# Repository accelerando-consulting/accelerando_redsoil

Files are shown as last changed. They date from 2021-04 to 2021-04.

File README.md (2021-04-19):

# Accelerando Redsoil

This is a simple breakout board for the eByte E73 module with nrf52840
microcontroller.  This board requires minimal parts, in fact it can
work with only the module and no other parts.

There is a space for a LED on the front (pin 1.04) and it is possible
to add buttons on the back by soldering to an IO pin and the ground plane.

The board can be used with Arduino (Sandeep Mistry's nrf port with the
generic nrf52 target), or Zephyr OS using the included board
definition.

There is also a board definition for the Adafruit nrf52 bootloader,
and for CircuitPython, which make the board a fully compliant
CircuitPython target.

The circuit board files (for KiCad 5) are included.

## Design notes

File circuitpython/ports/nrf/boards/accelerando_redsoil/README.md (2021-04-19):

# Accelerando Redsoil Breakout

The [Accelerando Redsoil](https://accelerando.com.au/) is a minimal
breakout board for eByte's ebyte_e73_2g4m08s1, which contains
an nrf52840, either with a chip antenna or IPX.   It breaks out all of
the outer castellated holes on the eByte module, and uses the under-board lands for
on-board parts (eg the LED on P0.04).

## CircuitPython Pin Defs

CircuitPython pin definitions hove to the NRF pin numbers, because
doing otherwise (like Sparkfun chose to do) breaks my brain.

<table>
</table>

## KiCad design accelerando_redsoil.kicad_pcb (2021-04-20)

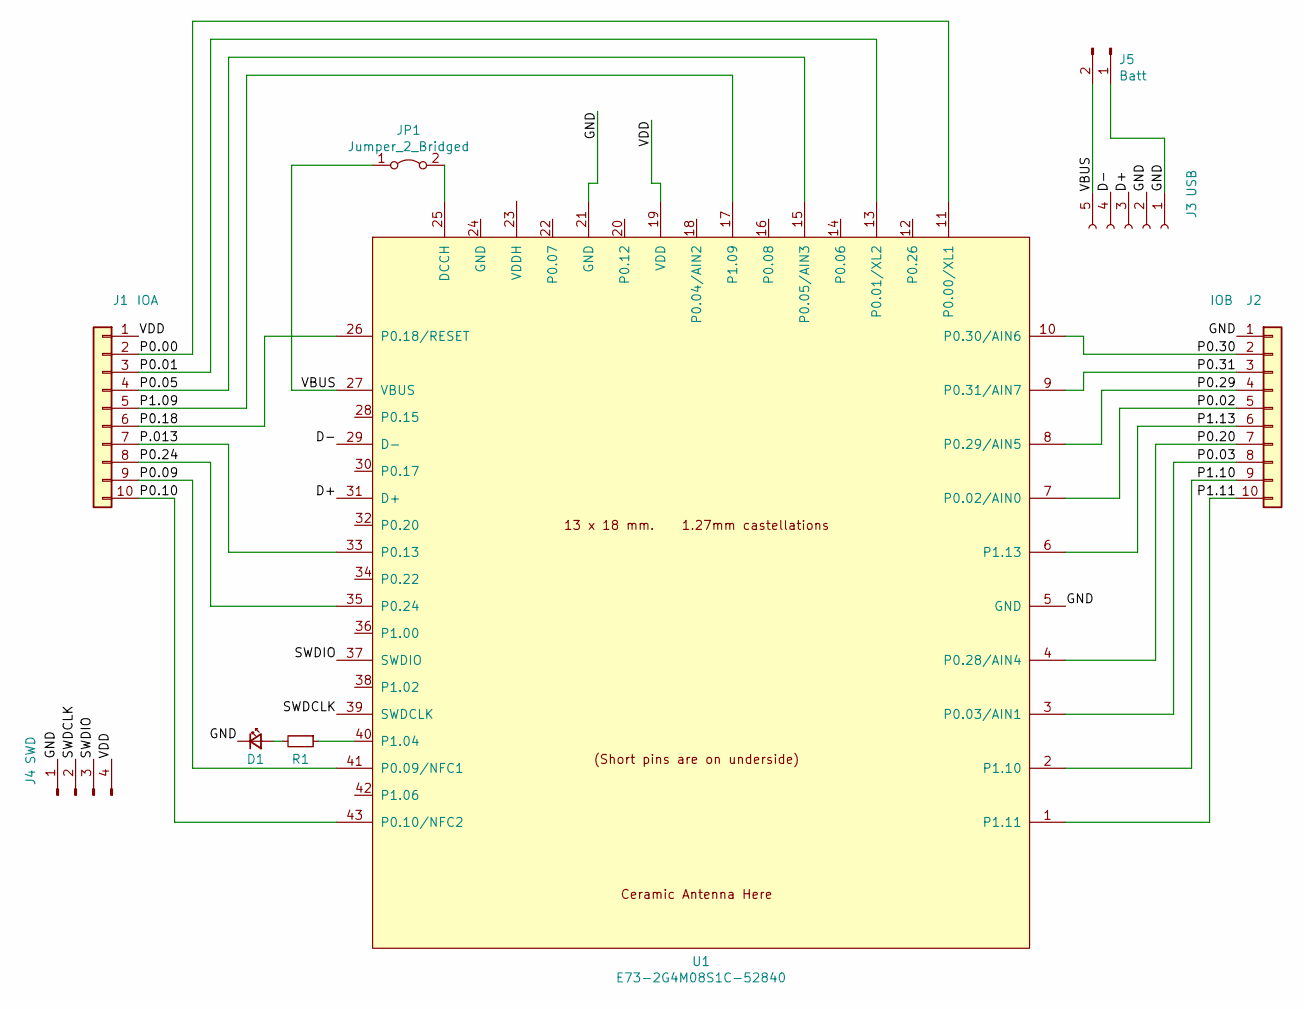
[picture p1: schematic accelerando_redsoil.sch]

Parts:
D1: LED_Small; LED_0603_1608Metric
J1: IOA; PinHeader_1x10_P2.54mm_Vertical
J2: IOB; PinHeader_1x10_P2.54mm_Vertical
J3: USB; PinHeader_1x05_P2.54mm_Vertical
J4: SWD; JST_PH_S4B-PH-K_1x04_P2.00mm_Horizontal
J5: Batt; PinHeader_1x02_P1.27mm_Vertical
JP1: Jumper_2_Bridged; SolderJumper-2_P1.3mm_Open_RoundedPad1.0x1.5mm
R1: R_Small; R_0603_1608Metric
U1: E73-2G4M08S1C-52840

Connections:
/D+: J3.3, U1.31 (D+)
/D-: J3.4, U1.29 (D-)
/GND: D1.1 (K), J2.1, J3.1, J3.2, J4.1, J5.1, U1.5 (GND), U1.21 (GND)
/P0.00: J1.2, U1.11 (P0.00/XL1)
/P0.01: J1.3, U1.13 (P0.01/XL2)
/P0.02: J2.5, U1.7 (P0.02/AIN0)
/P0.03: J2.8, U1.3 (P0.03/AIN1)
/P0.05: J1.4, U1.15 (P0.05/AIN3)
/P0.09: J1.9, U1.41 (P0.09/NFC1)
/P0.10: J1.10, U1.43 (P0.10/NFC2)
/P0.18: J1.6, U1.26 (P0.18/RESET)
/P0.20: J2.7, U1.4 (P0.28/AIN4)
/P0.24: J1.8, U1.35 (P0.24)
/P0.29: J2.4, U1.8 (P0.29/AIN5)
/P0.30: J2.2, U1.10 (P0.30/AIN6)
/P0.31: J2.3, U1.9 (P0.31/AIN7)
/P1.09: J1.5, U1.17 (P1.09)
/P1.10: J2.9, U1.2 (P1.10)
/P1.11: J2.10, U1.1 (P1.11)
/P1.13: J2.6, U1.6 (P1.13)
/P.013: J1.7, U1.33 (P0.13)
/SWDCLK: J4.2, U1.39 (SWDCLK)
/SWDIO: J4.3, U1.37 (SWDIO)
/VBUS: J3.5, J5.2, JP1.1 (A), U1.27 (VBUS)
/VDD: J1.1, J4.4, U1.19 (VDD)
unnamed: D1.2 (A), R1.2
unnamed: JP1.2 (B), U1.25 (DCCH)
unnamed: R1.1, U1.40 (P1.04)

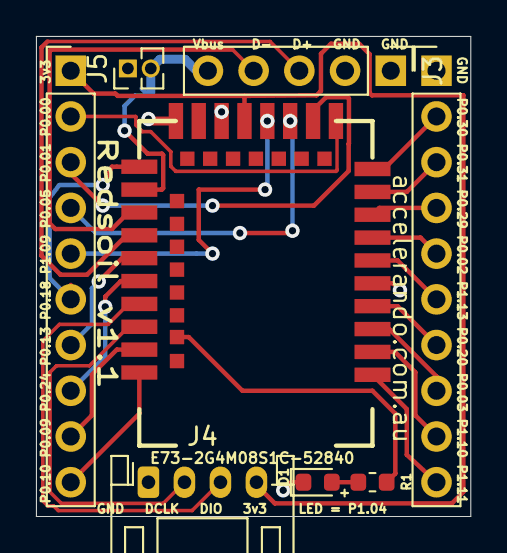
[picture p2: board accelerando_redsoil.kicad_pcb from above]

Board: 2 copper layers, 24.1 x 26.7 mm, 9 parts (1 on the bottom side), 28 nets.

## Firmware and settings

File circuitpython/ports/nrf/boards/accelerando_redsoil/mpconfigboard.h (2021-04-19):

/*
 * This file is part of the MicroPython project, http://micropython.org/
 *
 * The MIT License (MIT)
 *
 * Copyright (c) 2016 Glenn Ruben Bakke
 *
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
 * THE SOFTWARE IS PROVIDED "AS IS", WITHOUT WARRANTY OF ANY KIND, EXPRESS OR
 * IMPLIED, INCLUDING BUT NOT LIMITED TO THE WARRANTIES OF MERCHANTABILITY,
 * FITNESS FOR A PARTICULAR PURPOSE AND NONINFRINGEMENT. IN NO EVENT SHALL THE
 * AUTHORS OR COPYRIGHT HOLDERS BE LIABLE FOR ANY CLAIM, DAMAGES OR OTHER
 * LIABILITY, WHETHER IN AN ACTION OF CONTRACT, TORT OR OTHERWISE, ARISING FROM,
 * OUT OF OR IN CONNECTION WITH THE SOFTWARE OR THE USE OR OTHER DEALINGS IN
 * THE SOFTWARE.
 */

#include "nrfx/hal/nrf_gpio.h"

#define MICROPY_HW_BOARD_NAME       "Accelerando Redsoil"
#define MICROPY_HW_MCU_NAME         "nRF52840"

#define DEFAULT_I2C_BUS_SCL         (&pin_P0_29)
#define DEFAULT_I2C_BUS_SDA         (&pin_P0_02)

#define DEFAULT_SPI_BUS_SCK         (&pin_P0_05)
#define DEFAULT_SPI_BUS_MOSI        (&pin_P0_00)
#define DEFAULT_SPI_BUS_MISO        (&pin_P0_01)

#define DEFAULT_UART_BUS_RX         (&pin_P0_31)
#define DEFAULT_UART_BUS_TX         (&pin_P0_30)

/* Note: Flash chip is not provided on Accelerando Redsoil Mini.
 * Leaving this as a reminder for future/similar versions of the board. */
// Flash operation mode is determined by MICROPY_QSPI_DATAn pin configuration.
// A pin config is valid if it is defined and its value is not 0xFF.
// Quad   mode: If all DATA0 --> DATA3 are valid
// Dual   mode: If DATA0 and DATA1 are valid while either DATA2 and/or DATA3 are invalid
// Single mode: If only DATA0 is valid
/*#if QSPI_FLASH_FILESYSTEM
#define MICROPY_QSPI_DATA0                NRF_GPIO_PIN_MAP(0, 20)
#define MICROPY_QSPI_DATA1                NRF_GPIO_PIN_MAP(0, 21)
#define MICROPY_QSPI_DATA2                NRF_GPIO_PIN_MAP(0, 22)
#define MICROPY_QSPI_DATA3                NRF_GPIO_PIN_MAP(0, 23)
#define MICROPY_QSPI_SCK                  NRF_GPIO_PIN_MAP(0, 19)
#define MICROPY_QSPI_CS NRF_GPIO_PIN_MAP(0, 17)
#endif

#if SPI_FLASH_FILESYSTEM
#define SPI_FLASH_MOSI_PIN &pin_P0_20
#define SPI_FLASH_MISO_PIN &pin_P0_21
#define SPI_FLASH_SCK_PIN &pin_P0_19
#define SPI_FLASH_CS_PIN &pin_P0_17
#endif*/

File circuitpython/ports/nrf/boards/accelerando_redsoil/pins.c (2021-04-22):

#include "shared-bindings/board/__init__.h"

STATIC const mp_rom_map_elem_t board_module_globals_table[] = {

    // left hand side header top-to-bottom
    { MP_ROM_QSTR(MP_QSTR_D0), MP_ROM_PTR(&pin_P0_00) },
    { MP_ROM_QSTR(MP_QSTR_D1), MP_ROM_PTR(&pin_P0_01) },
    { MP_ROM_QSTR(MP_QSTR_D5), MP_ROM_PTR(&pin_P0_05) },
    { MP_ROM_QSTR(MP_QSTR_D41), MP_ROM_PTR(&pin_P1_09) },
    { MP_ROM_QSTR(MP_QSTR_D18), MP_ROM_PTR(&pin_P0_18) },
    { MP_ROM_QSTR(MP_QSTR_D13), MP_ROM_PTR(&pin_P0_13) },
    { MP_ROM_QSTR(MP_QSTR_D24), MP_ROM_PTR(&pin_P0_24) },
    { MP_ROM_QSTR(MP_QSTR_D9), MP_ROM_PTR(&pin_P0_09) },
    { MP_ROM_QSTR(MP_QSTR_D10), MP_ROM_PTR(&pin_P0_10) },


    // right-hand-side header, bottom to top
    { MP_ROM_QSTR(MP_QSTR_D43), MP_ROM_PTR(&pin_P1_11) },
    { MP_ROM_QSTR(MP_QSTR_D42), MP_ROM_PTR(&pin_P1_10) },
    { MP_ROM_QSTR(MP_QSTR_D3), MP_ROM_PTR(&pin_P0_03) },
    { MP_ROM_QSTR(MP_QSTR_D20), MP_ROM_PTR(&pin_P0_20) },
    { MP_ROM_QSTR(MP_QSTR_D45), MP_ROM_PTR(&pin_P1_13) },
    { MP_ROM_QSTR(MP_QSTR_D2), MP_ROM_PTR(&pin_P0_02) },
    { MP_ROM_QSTR(MP_QSTR_D29), MP_ROM_PTR(&pin_P0_29) },
    { MP_ROM_QSTR(MP_QSTR_D31), MP_ROM_PTR(&pin_P0_31) },
    { MP_ROM_QSTR(MP_QSTR_D30), MP_ROM_PTR(&pin_P0_30) },


    { MP_ROM_QSTR(MP_QSTR_SDA), MP_ROM_PTR(&pin_P0_29) },
    { MP_ROM_QSTR(MP_QSTR_SCL), MP_ROM_PTR(&pin_P0_02) },

    { MP_ROM_QSTR(MP_QSTR_MISO), MP_ROM_PTR(&pin_P0_01) },
    { MP_ROM_QSTR(MP_QSTR_MOSI), MP_ROM_PTR(&pin_P0_00) },
    { MP_ROM_QSTR(MP_QSTR_SCK), MP_ROM_PTR(&pin_P0_05) },

    { MP_ROM_QSTR(MP_QSTR_LED1), MP_ROM_PTR(&pin_P1_04)  },

    { MP_ROM_QSTR(MP_QSTR_BUTTON1), MP_ROM_PTR(&pin_P0_13) },
    { MP_ROM_QSTR(MP_QSTR_BUTTON2), MP_ROM_PTR(&pin_P0_20) },

    { MP_ROM_QSTR(MP_QSTR_RX), MP_ROM_PTR(&pin_P0_31) },
    { MP_ROM_QSTR(MP_QSTR_TX), MP_ROM_PTR(&pin_P0_30) },

    { MP_ROM_QSTR(MP_QSTR_UART), MP_ROM_PTR(&board_uart_obj) },
    { MP_ROM_QSTR(MP_QSTR_SPI), MP_ROM_PTR(&board_spi_obj) },
    { MP_ROM_QSTR(MP_QSTR_QWIIC), MP_ROM_PTR(&board_i2c_obj) },
    { MP_ROM_QSTR(MP_QSTR_I2C), MP_ROM_PTR(&board_i2c_obj) },
};

MP_DEFINE_CONST_DICT(board_module_globals, board_module_globals_table);

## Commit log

2021-04-19 Accelerando Redsoil - Open Source nrf52840 breakout board
    [accelerando_redsoil.kicad_pcb, accelerando_redsoil.sch]
2021-04-19 Board definition for Adafruit bootloader
2021-04-19 Board definition for Circuit Python
2021-04-19 Board definition for Zephyr
2021-04-20 Redsoil PCB 1.1 - USB power, Battery conn, JST PH SWD
    [accelerando_redsoil.kicad_pcb, accelerando_redsoil.sch]
2021-04-22 Use underscore not hyphen in zephyr board name
2021-04-22 Fix the pin number of pin 1.11 in circuitpython
    [pins.c]

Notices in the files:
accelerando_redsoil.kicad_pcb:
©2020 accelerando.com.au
